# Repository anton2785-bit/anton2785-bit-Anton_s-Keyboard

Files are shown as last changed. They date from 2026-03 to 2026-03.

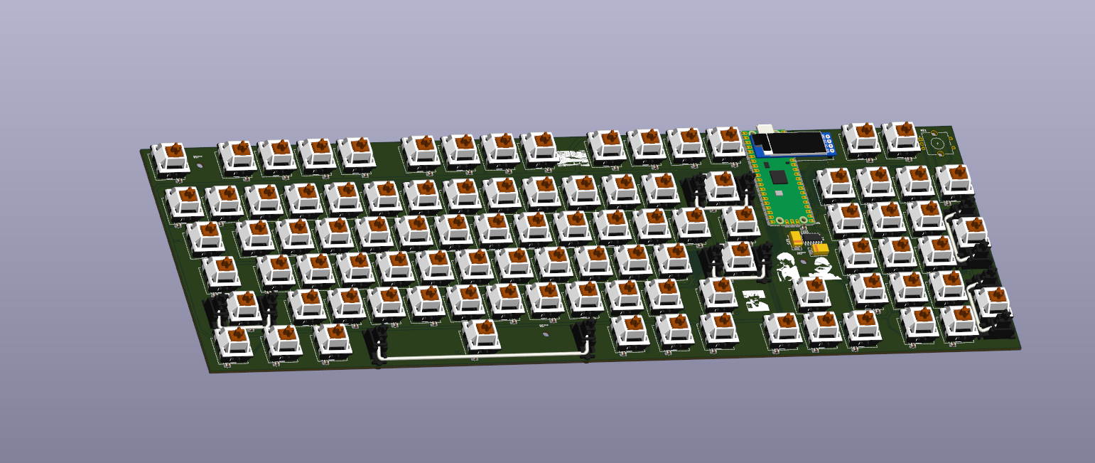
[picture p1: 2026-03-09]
Images/PCB assembly.png

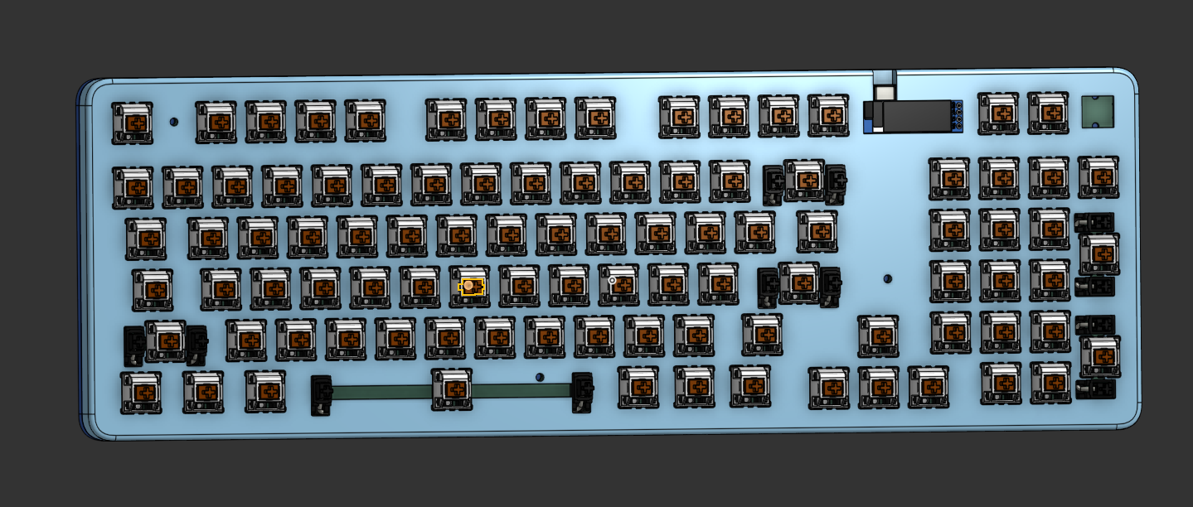
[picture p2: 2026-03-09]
Images/Keyboard assembly.png

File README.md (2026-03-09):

# Anton-s-Keyboard
---
# BOM

* Microcontroller (YD-RP 2040)
* Gateroon switches
* Hotswap module
* Gateroon stabilizer
* decoupling capacitors ( 100nF )
* 5V level shifter (74AHCT125)
* LEDs (SK 6812 mini E)
* keycaps
* Rotary encoder ( EC11E )
* Diodes ( 1N4148W )
* Oled screen ( 0.91 inch screen 128x32)
* Tantalum capacitor ( 470uF 6.3V D )
* Resistors ( Pack of many )
* Foam
* Coiled cable
---
# PCB

* The PCB was redone 1 time, so that it was better with the lenght of traces and minimising the resistance.
Top layer PCB
Back layer PCB

---
# 3D case

* The case isnt perfect, but for now it will work. When i get all of the parts for the keyboard and then I will have the ability to measuer all of the things I need to make the case more percise. 
Keyboard case

--- 
# Firmware
* The firmware will be changed once I get access to the microcontroller.
* The code now is generated by gemini. 


--- 
# Assembly steps
* First the smaller parts must be souldered first because it will be harder to soulder the smaller components once the larger ones are placed / souldered.
* Secondly the larger components are souldered.
* Thirdly the foam is placed in the bottom case.
* After that all of the other parts are placed on the foam and closed off with the top plate.
* Finaly the cable can be connected to the PC and keyboard.

--- 
# Credits

* Designed and built by (Anton/ Anton-2785-bit)
* Inspired by open‑source mechanical keyboard and hackpad communities (https://blueprint.hackclub.com/home).

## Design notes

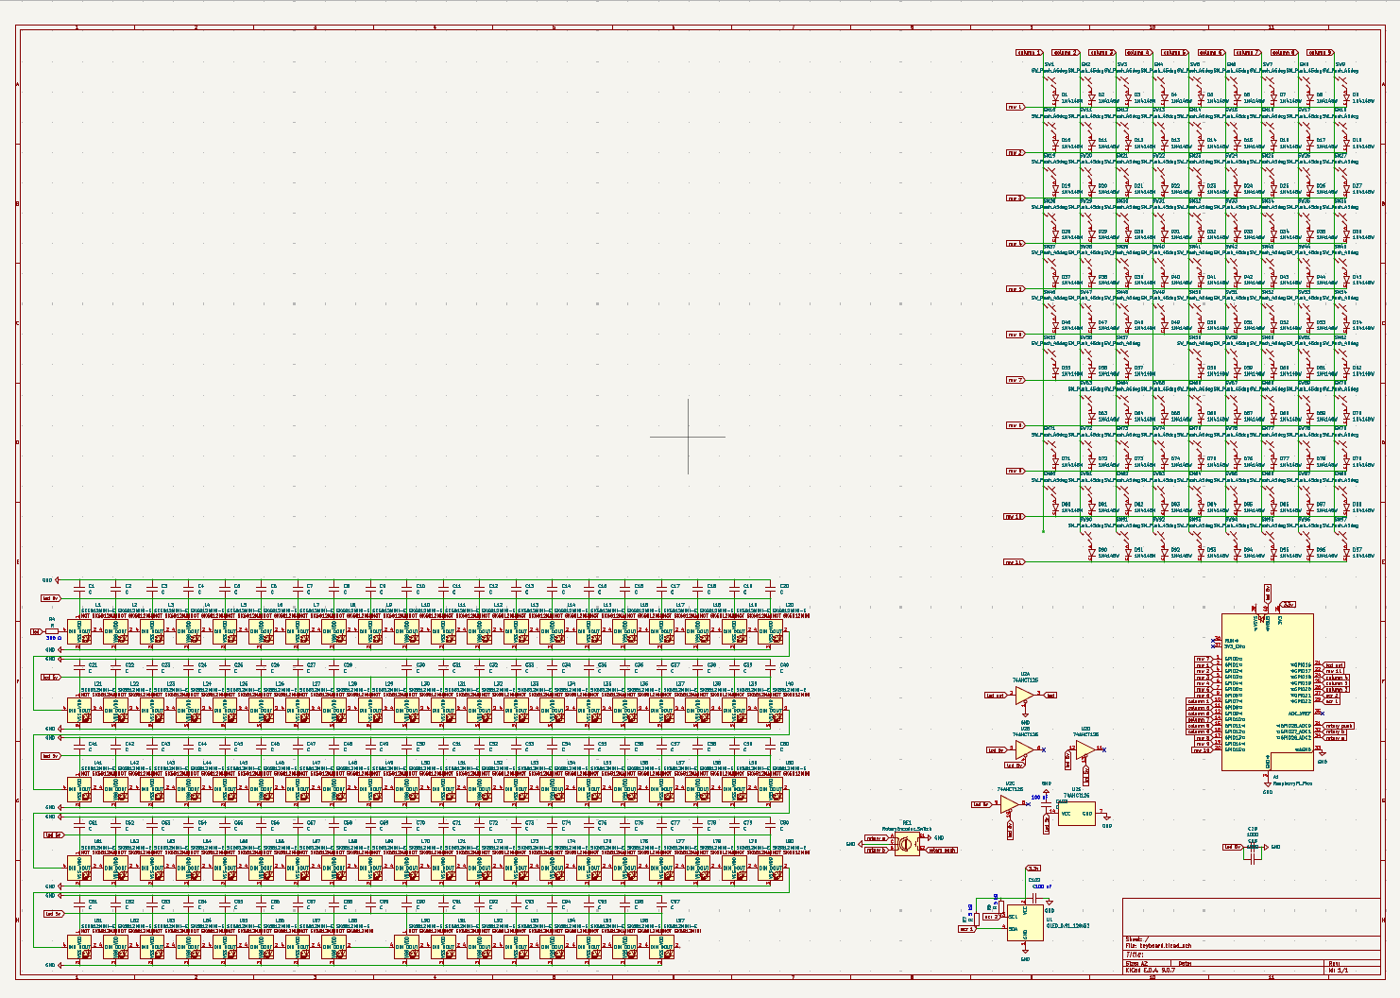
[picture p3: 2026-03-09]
Images/Schematic.png

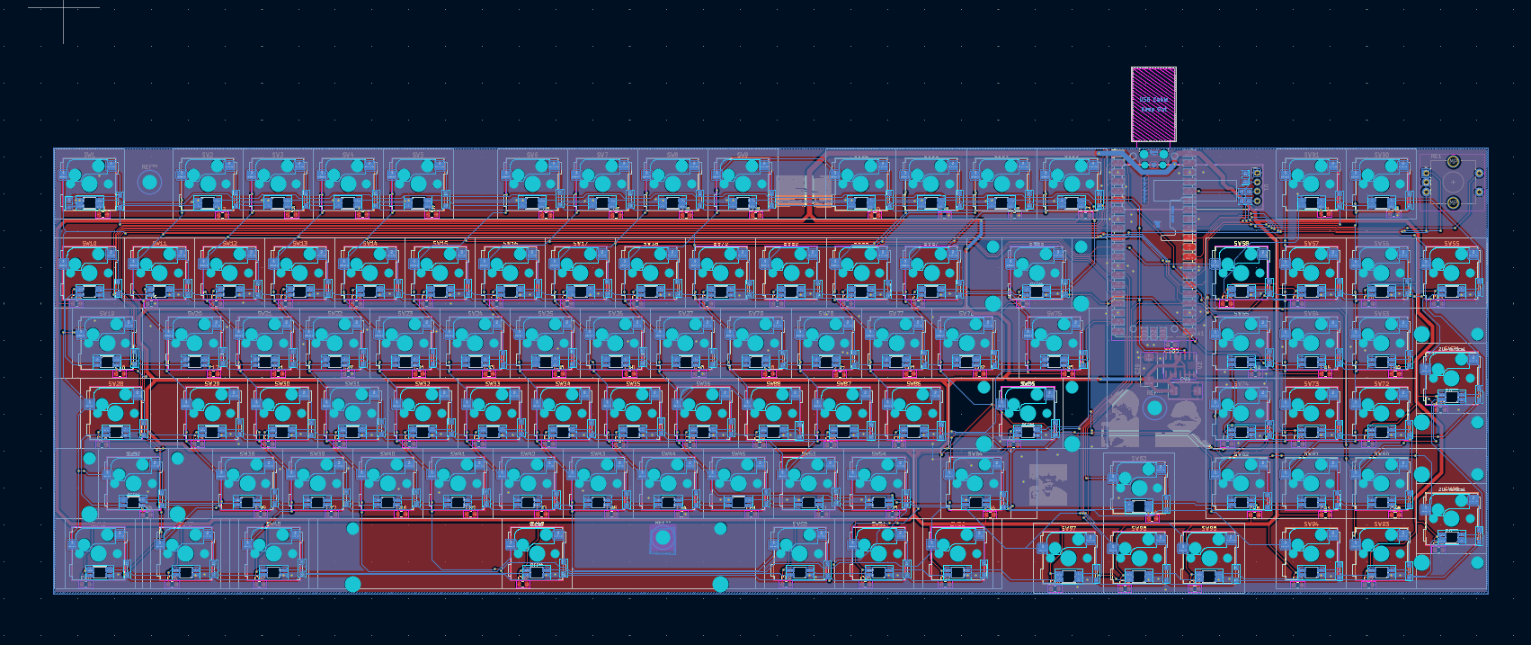
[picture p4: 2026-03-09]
Images/Back layer PCB.png

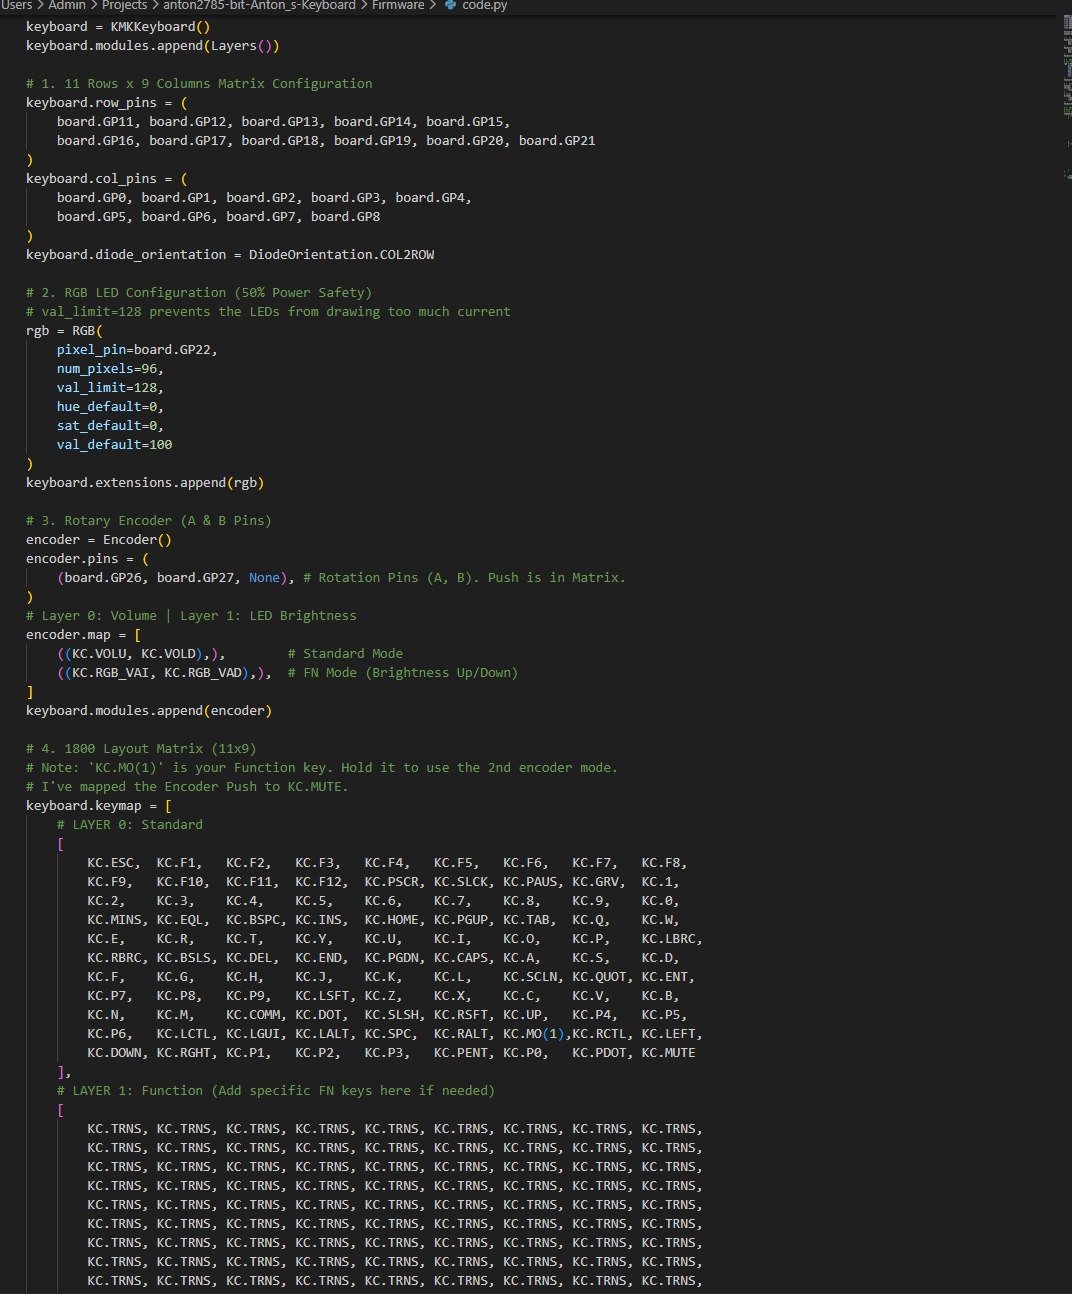
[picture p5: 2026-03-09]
Images/firmware code.png

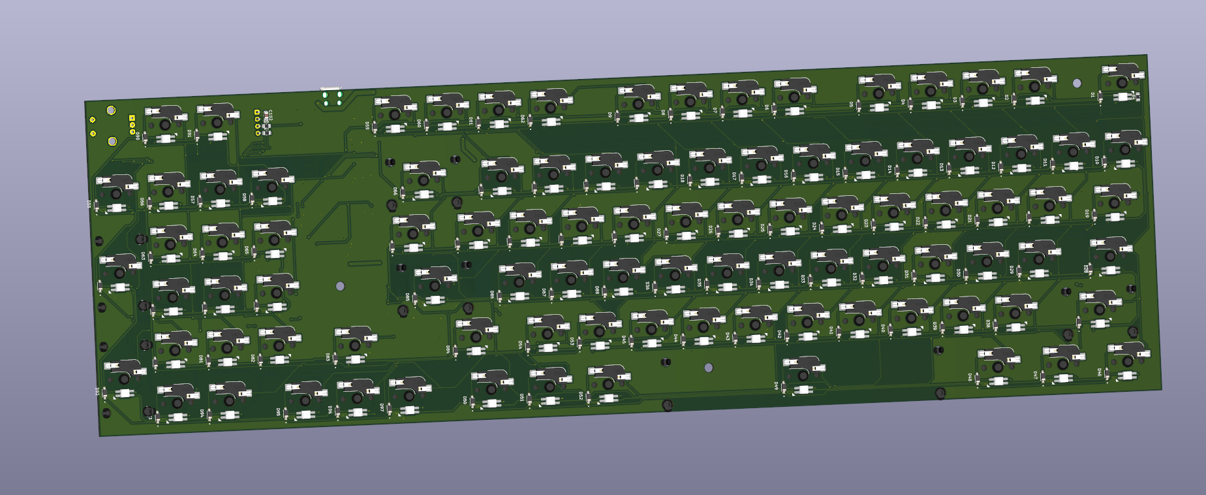
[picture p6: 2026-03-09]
Images/PCB 3D model.png

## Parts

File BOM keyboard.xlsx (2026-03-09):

Product name | Product description | Product link | Product price | Product amount | Product total
Microcontroller (YD-RP 2040) | The microcontroller for the keyboard | Aliexpress (https://www.aliexpress.com/item/1005005617180169.html?mp=1) | €2.94 | 1 | €2.94
Gateroon switches | These are the switches that you type on | Gateron (https://www.gateron.com/products/gateron-jupiter-switch-set?VariantsId=10736) | €29.00 | 1 | €31.94
Hotswap module | These modules allow for the easy change of the switches | Gateron (https://www.gateron.com/products/gateron-hot-swap-pcb-socket?VariantsId=10170) | €6.68 | 1 | €38.62
Gateroon stabilizer | makes the bigger switches not wable | gateron (https://www.gateron.com/products/gateron-pcb-mounted-stabilizer?VariantsId=10539) | €9.45 | 1 | €48.07
decoupling capacitors ( 100nF ) | The capacitors are for lowering the electrical noise before the LEDs | Aliexpress (https://www.aliexpress.com/item/1005007470747384.html?curPageLogUid=Welo3JfDNEL5) | €1.61 | 2 | €51.29
5V level shifter (74AHCT125) | A 5V level shifter for the data line on the LEDs | Aliexpress (https://www.aliexpress.com/item/1005010022053816.html?curPageLogUid=rUWakoUBMKlr) | €2.95 | 1 | €54.24
LEDs (SK 6812 mini E) | The LEDs bellow the switches | Aliexpress (https://www.aliexpress.com/item/1005008591589739.html) | €3.56 | 2 | €61.36
keycaps | Keycaps | Aliexpress (https://www.aliexpress.com/item/1005009417260572.html?mp=1&sourceType=620) | €15.78 | 1 | €77.14
Rotary encoder ( EC11E ) | A knob for twisting | Aliexpress (https://www.aliexpress.com/item/1005006111225091.html?mp=1) | €2.78 | 1 | €79.92
Diodes ( 1N4148W ) | Diodes, that stop form signal going back | Aliexpress (https://www.aliexpress.com/item/1005007160563285.html?curPageLogUid=tLoKi0NWvNsL) | €1.84 | 2 | €83.60
Oled screen ( 0.91 inch screen 128x32) | A mini screen for displaying information | Aliexpress (https://www.aliexpress.com/item/1005008640132638.html?curPageLogUid=1QPLEGb8Xexo) | €2.35 | 1 | €85.95
Tantalum capacitor ( 470uF 6.3V D ) | A bulk capacitor | Aliexpress (https://www.aliexpress.com/item/1005003379476726.html?mp=1) | €3.94 | 1 | €89.89
Resistors ( Pack of many ) | Resistors ( 4.7 kΩ and 350Ω) | Aliexpress (https://www.aliexpress.com/item/1005010759489629.html?mp=1) | €4.10 | 1 | €93.99
PCB | PCB | JLCPCB | €45.00 | 1 | €138.99
Foam | Used for making the keyboard sound betetr, its placed bellow the PCB | Aliexpress (https://www.aliexpress.com/item/1005003843877335.html?mp=1) | €7.77 | 1 | €146.76
Cable for keyboard | A cool coiled cable for the cable | Aliexpress (https://www.aliexpress.com/item/1005003567306738.html?mp=1) | €10.77 | 1 | €157.53

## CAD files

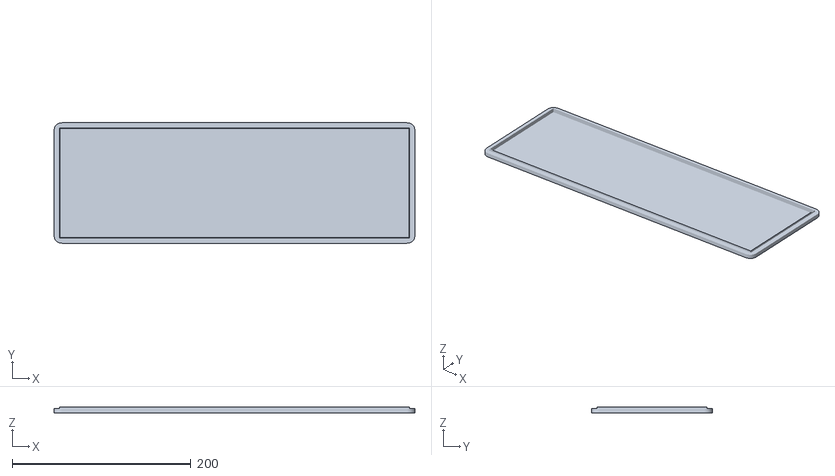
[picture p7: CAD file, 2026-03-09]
Production/Bottom case.stl
403.4 x 134.7 x 7.00

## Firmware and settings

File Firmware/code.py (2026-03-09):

import board
from kmk.kmk_keyboard import KMKKeyboard
from kmk.keys import KC
from kmk.scanners import DiodeOrientation
from kmk.extensions.RGB import RGB
from kmk.modules.encoder import Encoder
from kmk.modules.layers import Layers

keyboard = KMKKeyboard()
keyboard.modules.append(Layers())

# 1. 11 Rows x 9 Columns Matrix Configuration
keyboard.row_pins = (
    board.GP11, board.GP12, board.GP13, board.GP14, board.GP15, 
    board.GP16, board.GP17, board.GP18, board.GP19, board.GP20, board.GP21
)
keyboard.col_pins = (
    board.GP0, board.GP1, board.GP2, board.GP3, board.GP4, 
    board.GP5, board.GP6, board.GP7, board.GP8
)
keyboard.diode_orientation = DiodeOrientation.COL2ROW

# 2. RGB LED Configuration (50% Power Safety)
# val_limit=128 prevents the LEDs from drawing too much current
rgb = RGB(
    pixel_pin=board.GP22, 
    num_pixels=96, 
    val_limit=128, 
    hue_default=0, 
    sat_default=0, 
    val_default=100
)
keyboard.extensions.append(rgb)

# 3. Rotary Encoder (A & B Pins)
encoder = Encoder()
encoder.pins = (
    (board.GP26, board.GP27, None), # Rotation Pins (A, B). Push is in Matrix.
)
# Layer 0: Volume | Layer 1: LED Brightness
encoder.map = [
    ((KC.VOLU, KC.VOLD),),        # Standard Mode
    ((KC.RGB_VAI, KC.RGB_VAD),),  # FN Mode (Brightness Up/Down)
]
keyboard.modules.append(encoder)

# 4. 1800 Layout Matrix (11x9)
# Note: 'KC.MO(1)' is your Function key. Hold it to use the 2nd encoder mode.
# I've mapped the Encoder Push to KC.MUTE.
keyboard.keymap = [
    # LAYER 0: Standard
    [
        KC.ESC,  KC.F1,   KC.F2,   KC.F3,   KC.F4,   KC.F5,   KC.F6,   KC.F7,   KC.F8,
        KC.F9,   KC.F10,  KC.F11,  KC.F12,  KC.PSCR, KC.SLCK, KC.PAUS, KC.GRV,  KC.1,
        KC.2,    KC.3,    KC.4,    KC.5,    KC.6,    KC.7,    KC.8,    KC.9,    KC.0,
        KC.MINS, KC.EQL,  KC.BSPC, KC.INS,  KC.HOME, KC.PGUP, KC.TAB,  KC.Q,    KC.W,
        KC.E,    KC.R,    KC.T,    KC.Y,    KC.U,    KC.I,    KC.O,    KC.P,    KC.LBRC,
        KC.RBRC, KC.BSLS, KC.DEL,  KC.END,  KC.PGDN, KC.CAPS, KC.A,    KC.S,    KC.D,
        KC.F,    KC.G,    KC.H,    KC.J,    KC.K,    KC.L,    KC.SCLN, KC.QUOT, KC.ENT,
        KC.P7,   KC.P8,   KC.P9,   KC.LSFT, KC.Z,    KC.X,    KC.C,    KC.V,    KC.B,
        KC.N,    KC.M,    KC.COMM, KC.DOT,  KC.SLSH, KC.RSFT, KC.UP,   KC.P4,   KC.P5,
        KC.P6,   KC.LCTL, KC.LGUI, KC.LALT, KC.SPC,  KC.RALT, KC.MO(1),KC.RCTL, KC.LEFT,
        KC.DOWN, KC.RGHT, KC.P1,   KC.P2,   KC.P3,   KC.PENT, KC.P0,   KC.PDOT, KC.MUTE
    ],
    # LAYER 1: Function (Add specific FN keys here if needed)
    [
        KC.TRNS, KC.TRNS, KC.TRNS, KC.TRNS, KC.TRNS, KC.TRNS, KC.TRNS, KC.TRNS, KC.TRNS,
        KC.TRNS, KC.TRNS, KC.TRNS, KC.TRNS, KC.TRNS, KC.TRNS, KC.TRNS, KC.TRNS, KC.TRNS,
        KC.TRNS, KC.TRNS, KC.TRNS, KC.TRNS, KC.TRNS, KC.TRNS, KC.TRNS, KC.TRNS, KC.TRNS,
        KC.TRNS, KC.TRNS, KC.TRNS, KC.TRNS, KC.TRNS, KC.TRNS, KC.TRNS, KC.TRNS, KC.TRNS,
        KC.TRNS, KC.TRNS, KC.TRNS, KC.TRNS, KC.TRNS, KC.TRNS, KC.TRNS, KC.TRNS, KC.TRNS,
        KC.TRNS, KC.TRNS, KC.TRNS, KC.TRNS, KC.TRNS, KC.TRNS, KC.TRNS, KC.TRNS, KC.TRNS,
        KC.TRNS, KC.TRNS, KC.TRNS, KC.TRNS, KC.TRNS, KC.TRNS, KC.TRNS, KC.TRNS, KC.TRNS,
        KC.TRNS, KC.TRNS, KC.TRNS, KC.TRNS, KC.TRNS, KC.TRNS, KC.TRNS, KC.TRNS, KC.TRNS,
        KC.TRNS, KC.TRNS, KC.TRNS, KC.TRNS, KC.TRNS, KC.TRNS, KC.TRNS, KC.TRNS, KC.TRNS,
        KC.TRNS, KC.TRNS, KC.TRNS, KC.TRNS, KC.TRNS, KC.TRNS, KC.TRNS, KC.TRNS, KC.TRNS,
        KC.TRNS, KC.TRNS, KC.TRNS, KC.TRNS, KC.TRNS, KC.TRNS, KC.TRNS, KC.TRNS, KC.TRNS
    ]
]

if __name__ == '__main__':
    keyboard.go()

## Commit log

2026-03-09 File update
    [BOM keyboard.xlsx, Bottom case.stl, keyboard.kicad_sch]
2026-03-09 Add PCB details and images to README
    Added PCB section with details on redesign and images.
2026-03-09 Update README with PCB and case information
    Added details about PCB and 3D case.
